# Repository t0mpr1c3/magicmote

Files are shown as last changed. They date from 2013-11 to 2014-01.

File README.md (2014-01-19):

Magic Mote
==========

Wireless sensor node interfacing low-power [MSP430G2553 microcontroller]("http://www.ti.com/product/msp430g2553") with [Nordic NRF24L01+]("https://www.sparkfun.com/datasheets/Components/SMD/nRF24L01Pluss_Preliminary_Product_Specification_v1_0.pdf") 2.4 GHz RF module.

Layout designed for easy compatibility with [msprf24]("https://github.com/spirilis/msprf24") and [Enrf24]("https://github.com/spirilis/Enrf24") libraries by Spirilis.

Features
--------

* Unregulated power input from 2xAA or CR2032 Lithium coin cell
* 3.5mm jack socket/3 pin header with optional 2K2 pullup resistor on data line for 1-wire devices
* 4-pin header suitable for DHT22 temperature/humidity sensor
* Analogue input with low pass filter
* Tactile switch (can be mounted either side of board)
* Optional watch crystal
* Programming/serial header
* Dimensions suit panelization 24.5 x 49.00 mm footprint (2 panels on 5x5 cm)

Version history
---------------

_MO01_

First version.
Erratum: TXD and RXD labels permuted on 6-pin programming/serial header.

_MO02_

Switched TXD and RXD labels on 6-pin programming/serial header.
Moved from 3x8mm to 2x6mm watch crystal, with isolated ground plane, removed external capacitors.
Removed superfluous pulldown resistor on TST.
Changed programming/serial header to 2x3 footprint.
Changed switch to smaller SMD footprint and moved to more accessible position at side of board.

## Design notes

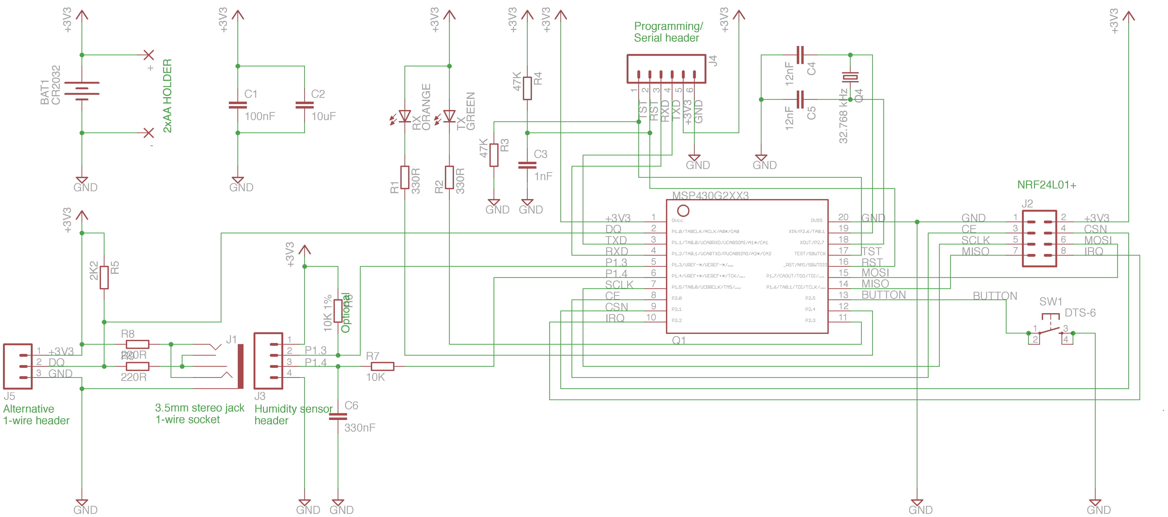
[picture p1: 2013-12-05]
hardware/MO01/MO01-sch.png

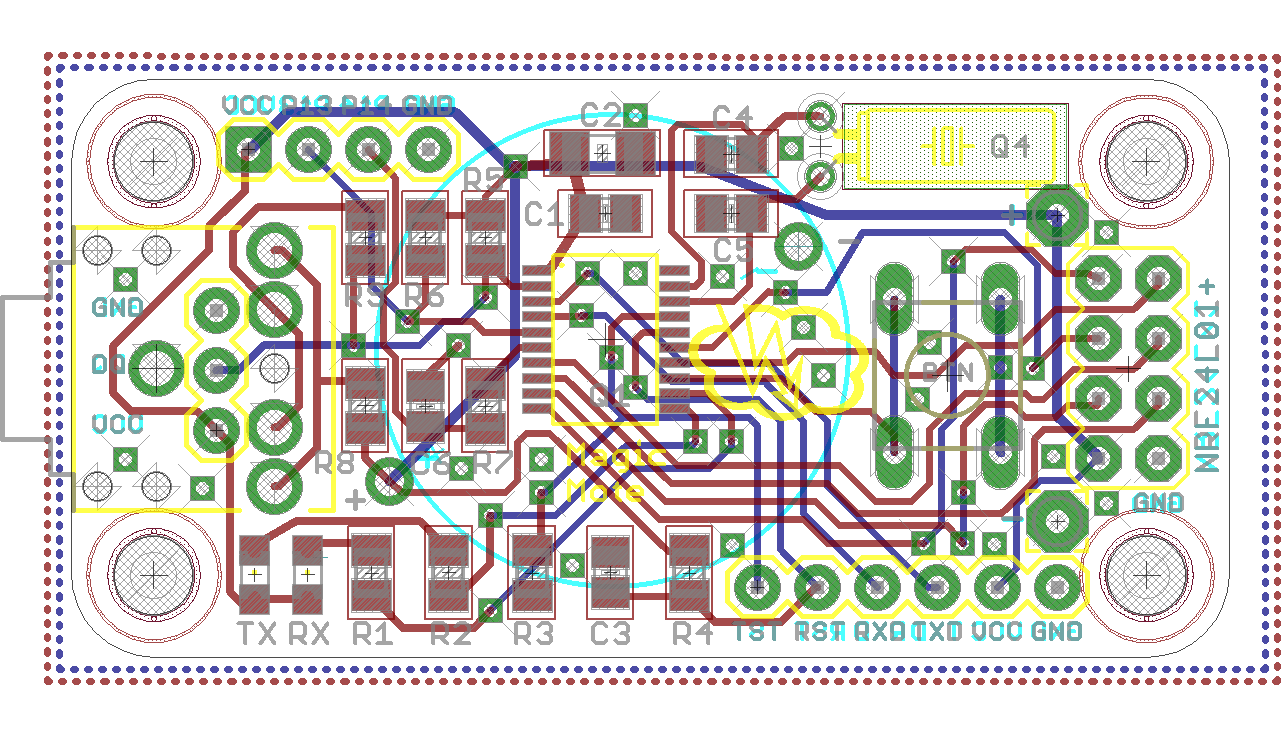
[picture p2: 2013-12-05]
hardware/MO01/MO01-brd.png

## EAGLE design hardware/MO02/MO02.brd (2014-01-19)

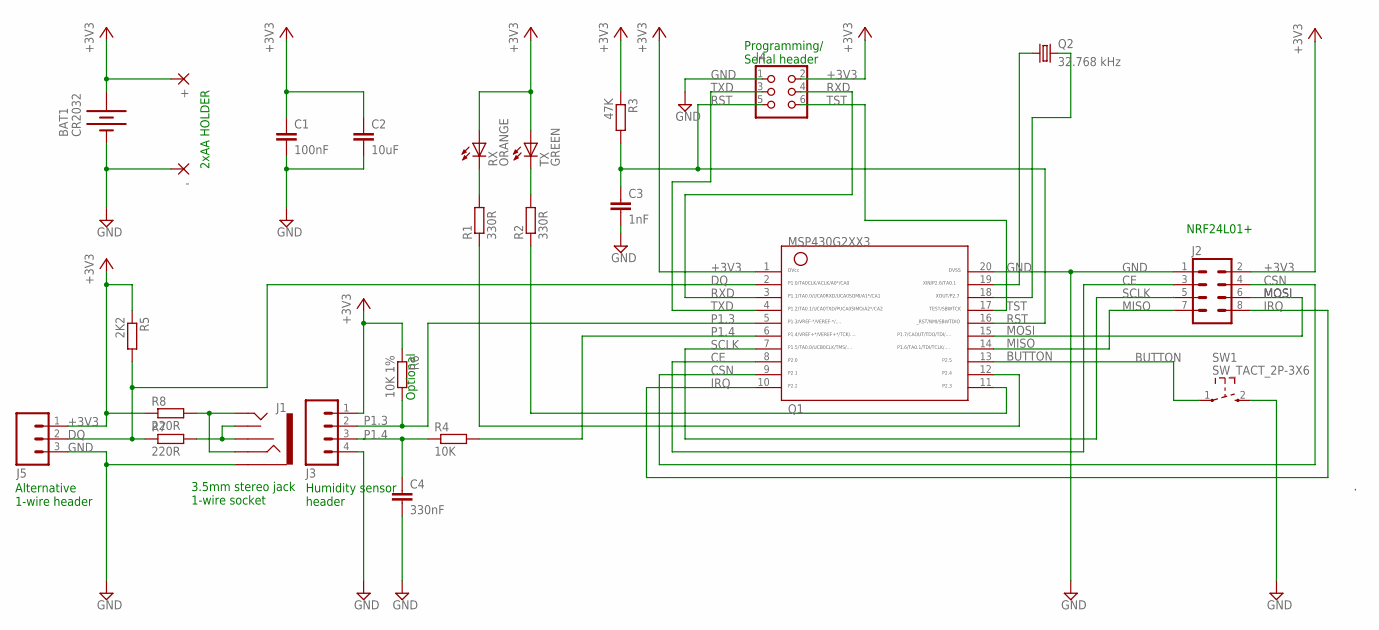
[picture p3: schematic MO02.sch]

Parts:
+: 2,54/1,0
-: 2,54/1,0
BAT1: CR2032; BATTCOM_20MM_PTH
C1: 100nF; C0805
C2: 10uF; C1206
C3: 1nF; C0805
C4: 330nF; C0805
J1: AUDIO-JACK2PTH; AUDIO-JACK
J2: M04X2; 2X4
J3: M04PTH; 1X04
J4: CON_HEADER_2X03-PTH; M2X3
J5: M03PTH; 1X03
Q1: G2XX3---PW20; PW20
Q2: 32.768 kHz; TC26H
R1, R2: 330R; M0805
R3: 47K; M0805
R4: 10K; M0805
R5: 2K2; M0805
R6: 10K 1%; M0805
R7, R8: 220R; M0805
RX: ORANGE; CHIPLED_0805
SW1: SW_TACT_2P-3X6; SW_TACT_3X6
TX: GREEN; CHIPLED_0805

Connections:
+3V3: +.1, BAT1.1 (+), C1.1, C2.1, J2.2, J3.1, J4.2, J5.1, Q1.1, R3.1, R5.1, R6.1, R8.1, RX.A, TX.A
BUTTON: Q1.13, SW1.1
CE: J2.3, Q1.8
CSN: J2.4, Q1.9
DQ: J5.2, Q1.2, R5.2, R7.1
GND: -.1, BAT1.2 (-), C1.2, C2.2, C3.2, C4.2, J1.SLEEVE, J2.1, J3.4, J4.1, J5.3, Q1.20, SW1.2 (3)
IRQ: J2.8, Q1.10
MISO: J2.7, Q1.14
MOSI: J2.6, Q1.15
unnamed: R2.2, TX.C
unnamed: R1.2, RX.C
unnamed: Q1.11, R2.1
unnamed: J1.RSH, J1.TSH, R7.2
unnamed: Q1.12, R1.1
unnamed: J1.RING, J1.TIP, R8.2
unnamed: C4.1, J3.3, R4.1
P1.3: J3.2, Q1.5, R6.2
P1.4: Q1.6, R4.2
P2.6: Q1.19, Q2.1
P2.7: Q1.18, Q2.2
RST: C3.1, J4.5, Q1.16, R3.2
RXD: J4.4, Q1.3
SCLK: J2.5, Q1.7
TST: J4.6, Q1.17
TXD: J4.3, Q1.4

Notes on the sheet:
3.5mm stereo jack 1-wire socket
NRF24L01+
Programming/ Serial header
Alternative 1-wire header
Humidity sensor header
Optional
2xAA HOLDER

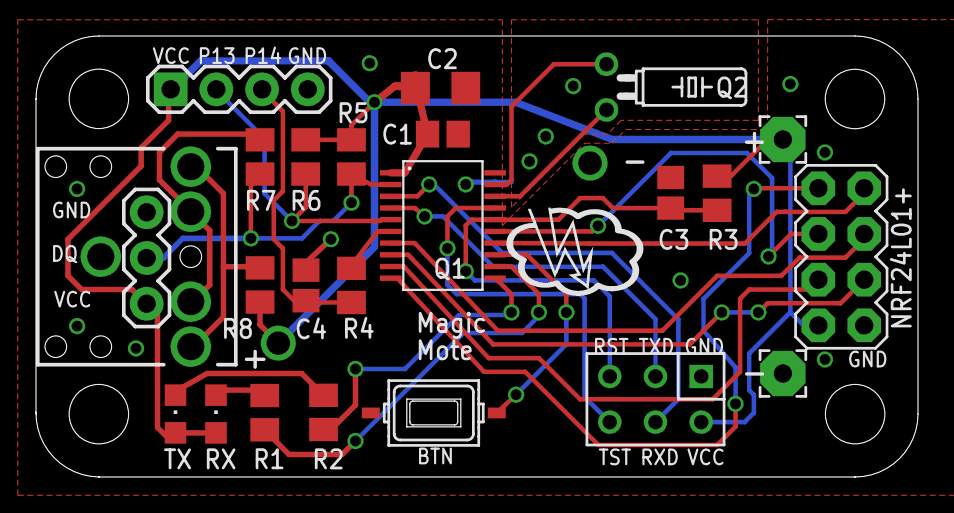
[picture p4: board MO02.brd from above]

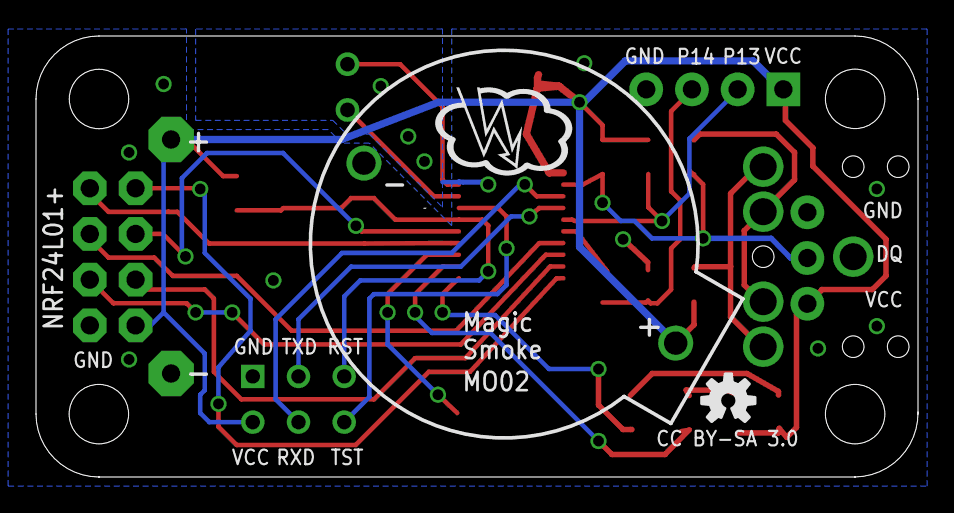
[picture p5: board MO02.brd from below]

Board: 2 copper layers, 49.0 x 24.5 mm, 30 parts (2 on the bottom side), 25 nets.

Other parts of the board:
U$1: OSHW-LOGO-S
U$2, U$3, U$4, U$5: STAND-OFF

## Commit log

2013-01-29 Initial commit hardware v1.0
    [wisenode_v1.0.brd, wisenode_v1.0.sch]
2013-01-29 schematic .png
    [wisenode_v1.0.brd, wisenode_v1.0.sch]
2013-01-29 fixed overlap of P2.5 header and coin cell holder
    [wisenode_v1.0.brd]
2013-02-01 BAT54A diode avoid charging battery
    [wisenode_v1.0.brd, wisenode_v1.0.sch]
2013-02-01 moved C7
    [wisenode_v1.0.brd]
2013-02-01 VCC wire fatter
    [wisenode_v1.0.brd]
2013-02-01 rejigged a few part labels
    [wisenode_v1.0.brd]
2013-02-06 changed LEDs, added push button
    [wisenode_v1.0.brd, wisenode_v1.0.sch]
2013-11-21 version WN01, first draft
    [WN01.brd, WN01.sch, WN01_2x_outline.brd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]
2013-11-29 MO01 first draft
    [MO01.GBL, MO01.GBO, MO01.GBP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]
2013-12-05 panelized order from Elecrow
    [MO01.GBL, MO01.GBO, MO01.GBP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]
2014-01-02 version MO02
    [MO02.brd, MO02.sch]
2014-01-07 2x6mm watch crystal, isolated ground plane, no external caps
    [MO02.brd, MO02.sch]
2014-01-07 removed pulldown resistor on TST
    [MO02.brd, MO02.sch]
2014-01-19 2x3 programming/serial header, SMD switch at side of board
    [MO02.brd, MO02.sch]

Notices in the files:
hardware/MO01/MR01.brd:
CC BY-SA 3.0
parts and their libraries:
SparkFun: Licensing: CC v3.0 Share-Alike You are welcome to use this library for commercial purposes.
